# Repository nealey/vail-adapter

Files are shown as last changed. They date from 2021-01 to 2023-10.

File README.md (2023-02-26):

---
Author: neale
Email: neale@woozle.org
License: MIT
---

# Vail Adapter: Morse Code Key/Paddle to USB

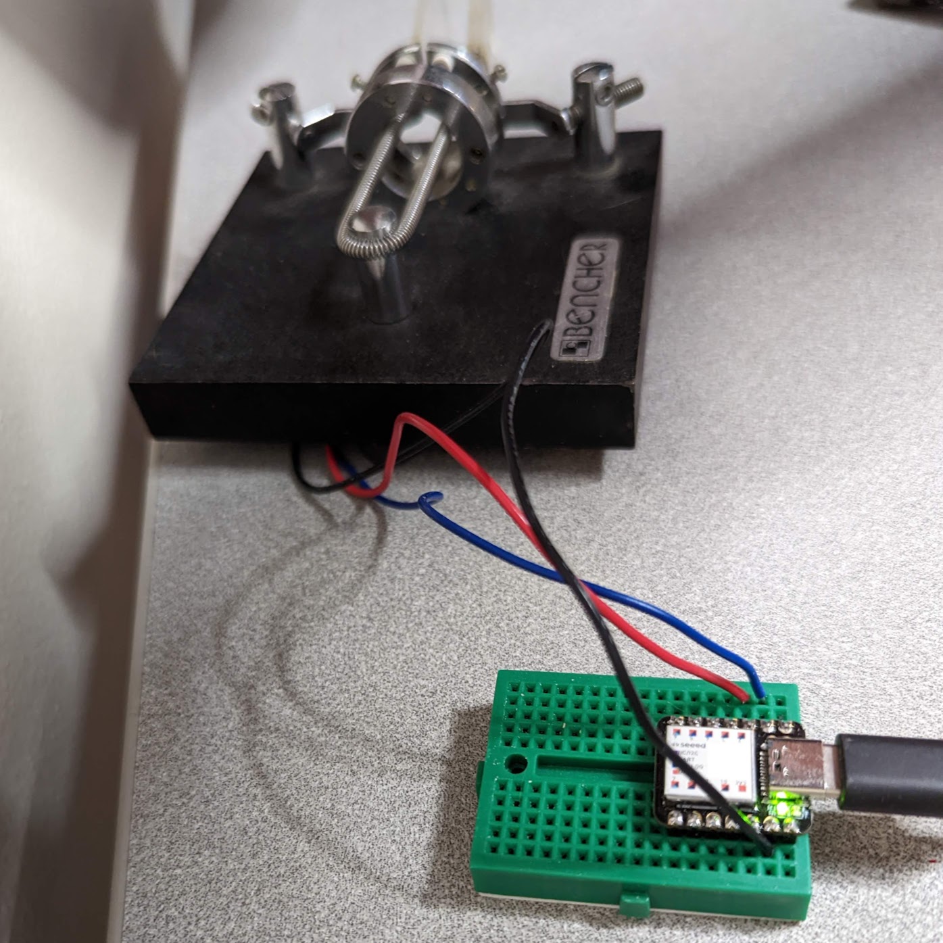
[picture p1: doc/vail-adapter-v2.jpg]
Vail adapter, assembled and connected


# Features

* Lets you key even if you move focus to another window
* Works with [Vail](https://vail.woozle.org/)
* Works with [VBand](https://hamradio.solutions/vband/), but the window has to remain focused
* Optional sidetone generator, which helps with latency
* Implements all nine keyer modes from Vail, in the adapter, so you lunatics can try to key at 50WPM with no latency issues
* Plays received signals in the adapter, so you can turn off your computer speaker
* Free firmware updates for life
* Can be wired up in about 5 minutes

[Vail Adapter benefits video](https://www.youtube.com/watch?v=XQ-mwdyLkOY) (4:46)

# Setting Up

* [Easy Setup](doc/easy-install.md)
* [Advanced Setup](doc/advanced-install.md)

# Future Work

Things I plan to add:

* [x] PCB to ease assembly and make a more robust shippable product
* [ ] Debug tone changes
* [ ] PCB v2 to get the speaker on pin 10 instead of pin 9
* [ ] Unplug detection: send a pulse out one pin and detect it on the T pin to reset straight-key detection

# Contributing
To contribute to this project please contact neale@woozle.org
https://id.arduino.cc/neale

# Similar projects

* Vail user Michele Giugliano's 
  [MorsePaddle2USB](https://github.com/mgiugliano/MorsePaddle2USB),
  which runs on a DigiSpark (attiny85). It only sends keystrokes, so you must keep the Vail
  window focused: you can't switch to other apps and still transimit.
* Ham Radio Solutions sells a 
  [USB Paddle Interface](https://hamradio.solutions/vband/)
  which appears to be very similar to Michele's project. You must keep the 
  Vail window focused.
* [CWKeyboard](https://github.com/kevintechie/CWKeyboard) looks almost 
  exactly the same as the VBand adapter.

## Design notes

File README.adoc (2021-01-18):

:Author: neale
:Email: neale@woozle.org
:Date: 2020-May-3
:Revision: 1
:License: MIT

= Project: USB Morse Adapter

image:https://lh3.googleusercontent.com/pw/ACtC-3d9xbLxL23QeLm-3gy3-Yt0VHE3IlQ-qyMDqTfdF6Bo7fHkkokACdIs68pmXevu14VzrrCeKj1JmRUiekUNiZe9J9rYIh_pTagvCbKSzpY8Ynp1m6cF4G_jTvti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["Vail adapter, assembled and connected",width=300,https://lh3.googleusercontent.com/pw/ACtC-3d9xbLxL23QeLm-3gy3-Yt0VHE3IlQ-qyMDqTfdF6Bo7fHkkokACdIs68pmXevu14VzrrCeKj1JmRUiekUNiZe9J9rYIh_pTagvCbKSzpY8Ynp1m6cF4G_jTvti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]

This translates Morse key inputs into USB events,
either MIDI or MIDI+Keyboard,
so you can use a computer.

I use this with an Internet morse code repeater I wrote,
available at https://vail.woozle.org/.
It will also work with [VBand](https://hamradio.solutions/vband/),
in MIDI+Keyboard mode.

This project requires an Arduino that can send USB.
The following should work:

=== Verified Working

* Seeeduino Xiao
* Arduino Micro
* KeeYees Pro Micro

=== Unverified but should work

Any USB-capable Arduino should be fine, including:

* Arduino Leonardo
* Arduino Zero
* Adafruit Trinket M0
* Adafruit GEMMA M0
* Adafruit Feather M0

You might even be able to get a Digispark (attiny85) to work,
but this may require a little hacking. Send me a patch, if you do!

== Step 1: Installation

If Arduino Create still exists when you're reading this,
you might be able to load up
https://create.arduino.cc/editor/neale/f94bb765-47bd-4bc4-9cbf-b978f7124bdc[my project]
and program your board without too much fuss.

Otherwise you are going to need to install the MidiUSB and Keyboard libraries.
These are highly popular libraries,
and there is much better documentation elsewhere on the Internet.

== Step 2: Assmble the circuit

=== For the impatient:

https://github.com/nealey/vail-adapter/wiki[Photos of assembled circuit]

Remember to jump pin 9 to ground for Firefox,
or VBand.

=== For the inquisitive:

Morse code keyers are very simple devices, 
they just connect two wires together.
You could use a button if you wanted to,
or even touch wires together.

The only real complication here is that some browsers
need to get keyboard events instead of musical instrument events.

=== Decide what browser you're going to use

Firefox needs a jumper between pin 9 and ground.
Just take a wire, and connect pin 9 directly to ground.
This puts the Arduino into "keyboard mode",
where it sends a comma for straight key,
and brackets for iambic.

If you don't connect pin 9 to ground,
the Arudino only sends MIDI (Musical Instrument Digital Interface)
events, so it looks like you hooked a piano up.
This works great in Chrome,
and lets you switch to other windows while still keying into vail.

=== Wire up your input device

Hook a straight key into ground on one side,
pin 10 on the other.
It's okay to leave pin 10 disconnected if you don't have a straight key.

Hook an iambic paddle in ground in the middle,
pins 11 and 12 on the outside posts.
It's okay to leave pins 11 and 12 disconnected if you don't have a paddle.

=== Using a headphone jack

If you prefer, you can wire a headphone jack up to GND, 11, and 12.
GND should be the sleeve, 11 the ring, and 12 the tip.

   o  --- 12
  |_| --- 11
  | | --- GND
  | |

Make sure any straight key you plug in has a TS adapter (mono plug):
this will short pin 11 to ground and signal to the Arduino to 
go into straight key mode.

You need to reset the Arduino if you change from an iambic to straight key.
On the micro, reset is a white button.

If you plug in your straight key and it looks like DAH is being held down,
it means you need to switch the connections to pins 11 and 12.

If you plug in your straight key and it looks like DIT is being held down,
it means you need to reset the Arduino to make it detect the key type again.

== Step 3: Load the code

Upload the code contained in this sketch on to your board.

== Step 4: Test it out

Make sure it's plugged in to your computer's USB port.

If you connected pin 9 to ground,
Open anything where you can type,
type in "hello", and hit the straight key.
You should see a comma after your hello.

Now you can open https://vail.woozle.org/,
click the "KEY" button once to let the browser know it's okay to make sound,
and you should be able to wail away on your new USB keyer.

=== License

This project is released under an MIT License.

Copyright © 2020 Neale Pickett
Copyright © 2013 thomasfredericks

Permission is hereby granted, free of charge, to any person obtaining a copy of
this software and associated documentation files (the "Software"), to deal in
the Software without restriction, including without limitation the rights to
use, copy, modify, merge, publish, distribute, sublicense, and/or sell copies of
the Software, and to permit persons to whom the Software is furnished to do so,
subject to the following conditions:

The above copyright notice and this permission notice shall be included in all
copies or substantial portions of the Software.

The software is provided "as is", without warranty of any kind, express or
implied, including but not limited to the warranties of merchantability, fitness
for a particular purpose, and noninfringement. In no event shall the authors or
copyright holders be liable for any claim, damages, or other liability, whether
in an action of contract, tort or otherwise, arising from, out of, or in
connection with the software or the use or other dealings in the software.

=== Contributing
To contribute to this project please contact neale@woozle.org
https://id.arduino.cc/neale

=== BOM

In addition to a key, some hookup wires, and a USB cable,
you only need a USB-capable Arduino: see above.

Since I don't know what might try to parse this section,
I'm calling for an Arduino Micro. But, really, many options
will work fine.

|===
| ID | Part name      | Part number | Quantity
| A1 | Arduino Micro  | ABX00053    | 1
|===

=== Help

This document is written in the _AsciiDoc_ format, a markup language to describe documents.
If you need help you can search the http://www.methods.co.nz/asciidoc[AsciiDoc homepage]
or consult the http://powerman.name/doc/asciidoc[AsciiDoc cheatsheet]

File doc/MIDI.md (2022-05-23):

# Vail MIDI Protocol

When it boots,
the Vail adapter sends left and right Control keyboard key up and down events.
It also shows up as a MIDI device.

The Vail web site sends MIDI control commands to enable MIDI keyer mode,
tells the keyer what sideband pitch to generate,
and can set the keyer mode.

## Controller 0 - MIDI Mode

`b0 00 ff` will enable MIDI mode and disable Keyboard mode

`b0 00 00` will enable Keyboard mode and disable MIDI mode

## Controller 1 - dit length

`b0 00 xx` will set the dit duration to `xx` times 2 milliseconds

## Controller 2 - sidetone note

`b0 00 xx` will play note `xx` as the sidetone note

## Program Change

`c0 xx` will change the keyer mode to `xx`.

### Keyer Modes

* 0: passthrough (sends C# and D for dit and dah)
* 1: cootie / straight key
* 2: bug
* 3: electric bug
* 4: single dot
* 5: ultimatic
* 6: plain iambic
* 7: iambic a
* 8: iambic b
* 9: keyahead

Any other mode will set to passthrough.

## Notes (key down / key up)

`90 00 xx` will begin playing note `xx`  
`80 00 xx` will end playing note `xx`

These work just like a regular MIDI synthesizer.

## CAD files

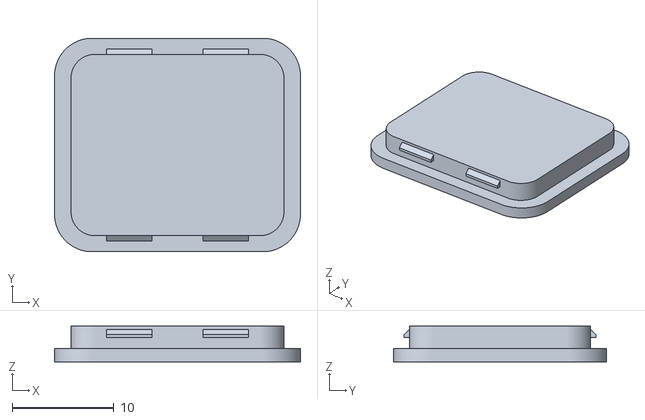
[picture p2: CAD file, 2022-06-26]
case/cap.stl
24.2 x 21.0 x 3.50

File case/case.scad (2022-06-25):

// Make circles lovely and round
$fa = 1; $fs = 0.1;

outer_dimensions = [24.2, 21, 25];
outer_radius = 3.7;
wall_width = [1.3, 1.3, 1.3];
inner_dimensions = outer_dimensions - (wall_width * 2);
inner_radius = outer_radius * 0.64;
z_elevate = [[0, 0, 0], [0, 0, 0], [0, 0, 0.5]]; // Multiply by this to bring bottom to z=0
center = [[-0.5, 0, 0], [0, -0.5, 0], [0, 0, 0]]; // Multiply by this to center something on the xy axes
xiao_elevation = 5.2; // Center of the PCB
pcb_thickness = 1.8;
channel = [16, 1, 1]; // Difensions of cap channel
channel_height = 2; // How far into the case the clips need to go
cap_thickness = 1.3;

module roundedcube(size=[1, 1, 1], center=false, r=0.5) {
    size = (size[0]==undef) ? [size, size, size] : size;
    cubeSize = [size[0] - 2*r, size[1] - 2*r, size[2]];

    translate(center ? [0,0,0] : size/2) {
        union() {
            cube([size[0], cubeSize[1], size[2]], center=true);
            cube([cubeSize[0], size[1], size[2]], center=true);
            for (ymul = [-0.5, 0.5]) {
                for (xmul = [-0.5, 0.5]) {
                    translate([cubeSize[0]*xmul, cubeSize[1]*ymul, 0]) cylinder(h=size[2], r=r, center=true);
                }
            }
        }
    }
}

module trs_support() {
    intersection() {
        cube([10, 30, 12], center=true);
        rotate(-45, [0, 1, 0]) cube([10, 30, 12], center=true);
    }
}

module usb_c() {
    cube([10, 6.5, 3.15], center=true);
    translate([0, -3.25, 0]) rotate(90, [0, 1, 0]) cylinder(d=3.15, h=10, center=true);
    translate([0, 3.25, 0]) rotate(90, [0, 1, 0]) cylinder(d=3.15, h=10, center=true);
}


module case() {
    difference() {
        translate((outer_dimensions * z_elevate) + ([0, 0, -1] * cap_thickness)) {
            difference() {
                roundedcube(outer_dimensions, center=true, r=outer_radius);
                roundedcube(inner_dimensions, center=true, r=inner_radius);
                translate(-outer_dimensions/2) cube([100, 100, cap_thickness]);
            }
        }

        // USB C port
        translate([inner_dimensions[0]/2, 0, 0]) {
            translate([0, 0, xiao_elevation - 3.15/2]) usb_c();
            cube([10, 9.65, xiao_elevation*2 - 3.15], center=true);
        }

    }
}

module body() {
    difference() {
        union() {
            case();

            // Add some supports
            intersection() {
                union() {
                    translate([13, 10, 13]) rotate(60, [0, 0, 1]) trs_support();
                    translate([13, -10, 13]) rotate(-60, [0, 0, 1]) trs_support();

                    // Shelf for board to rest against
                    difference() {
                        translate([-8, 0, xiao_elevation]) cube([6, 19, 4], center=true);
                        translate([-6, 0, xiao_elevation]) rotate(45, [0, 0, 1]) cube(15, center=true);
                    }
                }
                translate(outer_dimensions * center) roundedcube(outer_dimensions, r=outer_radius);
            }


            // Eyes
            translate([-12, 4, 18]) sphere(r=1.2);
            translate([-12, -4, 18]) sphere(r=1.2);
        }

        // Smirk grin
        intersection() {
            translate([0, 0, 11]) rotate(90, [0, 1, 0]) {
                difference() {
                    cylinder(h=50, d=20, center=true);
                    cylinder(h=50, d=19, center=true);
                }
            }
            translate([-18.7, 0, 0]) cube(7);
        }

        // Channel in the back to make it easier to squeeze in the XIAO
        translate([-4.5, 0, xiao_elevation]) intersection() {
            cube([13, 100, pcb_thickness], center=true);
            roundedcube(inner_dimensions, center=true, r=cap_thickness);
        }

        // Channels for bottom insertion part thingy
        for (i = [-0.5, 0.5]) {
            translate([0, inner_dimensions[1]*i, channel_height-channel[2]/2]) {
                cube(channel, center=true);
            }
        }

        // Paddle contacts
        translate([0, 0, 10]) {
            // 8-32x 1/4 screws
            rotate(90, [1, 0, 0]) cylinder(h=30, d=4.0, center=true);

            // Hookup wire
            translate([0, 0, -2.5]) cube([1, 30, 0.8], center=true);
        }

        // 3.5mm TRS jack
        translate([10, 0, 14]) rotate(90, [0, 1, 0]) cylinder(h=3, d=6.0);

        // Piezo buzzer
        translate([0, 0, 10]) {
            translate([-12, 3.5, 0]) cube([5, 1, 1], center=true);
            translate([-12, -3.5, 0]) cube([5, 1, 1], center=true);
        }
    }
}

module cap() {
    inner = inner_dimensions * 0.97; // leave 5% slop
    union() {
        intersection() {
            roundedcube(outer_dimensions, center=true, r=outer_radius);
            translate([0, 0, cap_thickness/2]) cube([100, 100, cap_thickness], center=true);
        }
        intersection() {
            roundedcube(inner, center=true, r=inner_radius);
            translate(center * inner) cube([100, 100, cap_thickness+2.2]);
        }
        difference() {
            union() {
                for (i = [-0.5, 0.5]) {
                    translate([0, inner[1]*i, cap_thickness + channel_height - channel[2]*0.4]) { // 40% of channel z for slop
                        difference() {
                            cube(channel, center=true);
                            translate([0, channel[1]*i, channel[2]/2]) rotate(90*i, [1, 0, 0]) {
                                cube([channel[0], channel[1], channel[2]], center=true);
                            }
                        }
                    }
                }
            }
            cube([5, 200, 200], center=true);
            for (i = [-1, 1]) {
                translate([9.5*i, 0, 0]) cube([5, 200, 200], center=true);
            }
        }
    }
}

if (TARGET == "body") {
    body();
} else if (TARGET == "cap") {
    cap();
} else if (true == true) {
    color([0, 0.5, 0.5]) body();
    color([0.5, 0, 0.5]) translate([0, 0, -cap_thickness]) cap();
} else {
    roundedcube(10);
}

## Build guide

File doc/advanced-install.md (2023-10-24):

# Advanced Install

In the Arduino IDE, edit [vail-adapter.ino](../vail-adapter.ino) with the pins
you want to use on your device. 

You will need the MidiUSB and Keyboard libraries installed.
You can do this through the Library manager.

Then compile and upload the sketch.

## Works with no source code changes

* Seeeduino Xiao SAMD21
* Adafruit Qt Py SAMD21

## Known to work with source code changes

* Arduino Micro
* KeeYees Pro Micro
* Arduino Leonardo
* Arduino Zero
* Adafruit Trinket M0
* Adafruit GEMMA M0
* Adafruit Feather M0

## Will Not Work!

The RP2040 chip will not work, because it lacks a USB MCU,
needed by the MIDIUSB library. 
I'm listing specific devices here
in the hopes that seeing them crossed out will prevent people from
making a purchasing mistake!

* ~~Seeeduino Xiao RP2040~~ Will not work!
* ~~Adafruit Qt Pi RP2040~~ Will not work!
* ~~Any RP2040 Device~~ Will not work!

# Advanced Wiring

XIAO Pinout

* GND: Ground
* D2: Dit
* D1: Dah
* D0: Straight Key
* D10: Speaker or Passive piezo buzzer
* A6: Capacative Dit
* A7: Capacative Dah
* A8: Capacative Straight Key

## Using a headphone jack

You can wire a headphone jack up to GND, D1, and D2.
GND should be the sleeve, D1 the ring, and D2 the tip.

     o  --- D2 (tip, dit)
    |_| --- D1 (ring, dah)
    | | --- GND (sleeve)
    | |

## Sidetone generator

If you connect a buzzer or speaker to pin 10 on one leg,
and ground on the other,
the adapter will beep when you press the straight key.

This will help a lot if there is a noticeable delay between when you press the key
and when your computer starts making a local beeping sound.

If you feel like no matter what you do,
you're always getting DAH with your straight key,
you should try this.

## Capacative Touch

The adapter works as a capacative touch sensor,
like a touch lamp.

You might wire these pins to screws or conductive pads. 
These can be used instead of, or in additon to, the normal pins D0, D1, and D2.

You do not need a ground wire with capacative touch!

* Pin A6: Dit capacative touch
* Pin A7: Dah capacative touch
* Pin A8: Straight key capacative touch

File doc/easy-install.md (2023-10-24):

# Easy Installation

1. Get a Seeeduino XIAO SAMD21
2. Download the most recent XIAO SAMD21 firmware from
[releases](https://github.com/nealey/vail-adapter/releases)
3. [Enter bootloader mode](https://wiki.seeedstudio.com/Seeeduino-XIAO/#enter-bootloader-mode)
4. Copy the firmware onto the XIAO SAMD21

[Wideo walkthrough of firmware upload](https://www.youtube.com/watch?v=IgOdkUe5SMY) (3:07)

If you would like to use a different microcontroller,
see the [advanced install instructions](advanced-install.md).

# Wiring

XIAO Pinout

* GND: Ground (usually in the middle of the paddle)
* Pin D2: Dit (usually left paddle)
* Pin D1: Dah (usually right paddle)

If you'd like to wire up a TRS (headphone) jack;
or take advantage of some of the adapters other features,
such as dedicated straight key, sidetone generation,
or capacative touch,
see the [advanced install instructions](advanced-install.md).

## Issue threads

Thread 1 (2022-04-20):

ESP32 Bluetooth as a future suggestion

mgiugliano, 2022-04-20:
ESP32 and its Bluetooth capabilities might be an interesting "wire-less" route to consider (although powering the device would still be cumbersome).

Thank you for your continued efforts and updates :-)

WrathPak, 2025-04-18:
Hi! We are exploring wifi as a method to wirelessly connect with the vail server. I haven't looked into bluetooth much yet but I think someone in the discord has - I'll check and see where they got with it.

WrathPak, 2025-09-20:
Just an update here, this is still being explored. We have a basic prototype hardware dev platform that can support this now.

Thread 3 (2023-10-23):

Does this work with the Seeed Xiao RP2040?

15medium, 2023-10-23:
Does this work with the Seeed Xiao RP2040?
https://wiki.seeedstudio.com/XIAO-RP2040/
Holding the boot button and plugging it in brings up the device but nothing happens when I copy the vail-adapter.xiao.uf2 file to it.
Thanks,
Paul VA3ZC

nealey, 2023-10-23:
No, it doesn't. Thanks for sending me a compile error log in private email, that saved me a bunch of time.

I've updated the documentation to specifically mention the M0 as the board to get. I hope nobody else has tried to get it on the wrong board!

nealey, 2023-10-23:
Fixed in https://github.com/nealey/vail-adapter/commit/36cc1384431d4a01a2066e536f0696d9a95e30b6

Closed 2023-10-23.

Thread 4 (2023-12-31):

Key down LED

g7kse, 2023-12-31:
Hi Neale,

Just ordering some parts for this and will be putting this in a small enclosure from [Hammond](https://www.hammfg.com/files/parts/pdf/1455C801RD.pdf) that I tend to use a bit so I'll adapt the PCB that's in the repo to slide in. Just wondering if adding a key down (TX'ing) LED is possible. The enclosure is 'desktop' so less like the smaller ones and there's obviously loads of space on the board

I would have thought using the buzzer might be a solution without changing code but then I noticed that Pin 10 might be used instead of Pin 9.

Before i go and fab up some PCB's can you let me know if the pin allocations will change and if its practical to take an LED off the buzzer pin?

nealey, 2024-01-01:
Yes, there's a bug with the current PCB, thanks for reminding me. I just opened #4 to track this problem. If you'd like to submit a patch to the PCB files, that would be super great! I'm not very adept at the software that generated them: I don't even remember what it's called.

You should be able to hook an LED up instead of a speaker: I think it uses the same PWM code, so the LED will not be full brightness. I don't have anything nearby to test this out, but if you have a microcontroller, go ahead and hook a sacrificial LED up to it and report back on how it went! The LED should be fine, but you never know, so don't use your favorite LED ;)

A very small code change would make a TX LED easy on another pin. You could `pinMode(8, OUTPUT)` and then, in beginTx and endTx, add `digitalWrite(8, true)` and `digitalWrite(8, false)` respectively, to get that LED going. I'd be glad to accept a patch adding this in, as well: but please use a `#define` instead of a hard-coded pin number :)

nealey, 2024-03-14:
@g7kse I finally got around to investigating: it appears the PCB files checked in have the speaker wired up to the correct pin. The board has 2023-01-22 silkscreened onto it: the ones I ordered are 2023-01-21. I must have realized shortly after I submitted the order that the pin was wrong, fixed it in git, and not bothered ordering a new batch, because I broke out every pin on top of the board anyway.

Anyway, I am strongly opposed to changing pins in the code, so feel encouraged to rely on the current allocations!

I'm going to close this issue, but I'd love to hear if you had any success wiring an LED to the buzzer pin.

nealey, 2024-03-14:
update: the pins are wrong on the part in kicad! I'll fix this.

Closed 2024-03-14.

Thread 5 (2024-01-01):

PCB has wrong pin wired to speaker

nealey, 2024-01-01:
Oops, I hooked pin 9 to the speaker: it should be pin 10.

Someone needs to change the PCB files to use the pin 10 instead!

nealey, 2024-03-14:
It looks like I actually made that change one day after I ordered my current batch of PCBs. The new design also moves the 3.5mm jack over and adds space for a piezo.

nealey, 2024-03-14:
The XIAO pins are incorrectly labelled, actually!

Closed 2024-03-14.

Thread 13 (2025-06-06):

User Changeable Key Bindings When in Keyboard Mode

Nehem11e, 2025-06-06:
A tool that was critical in my Morse code practice was Morse Mania. Unfortunately it uses a non standard key to listen trigger dits and dahs.  Left and Right square brackets “[“  and  “]”

It would be cool if you could use the vail repeater website, where other settings are changed, to set a key binding for the dits and dahs.  Have that setting save to the adapter and then have the adapter send out the new key building

WrathPak, 2025-06-08:
ok, vail repeater is updated at https://vail.fly.dev/ - here is the tool to change it. it is ugly and needs some work, but works.

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

this was kinda  ahuge change to keyboard mode so we should test it a lot
will only accept letters, [ ] / \ leftcontrl right contrl and shift keys as key bindings right now. and there is no error feedback on the ui yet.

[xiao_non_pcb.uf2.zip](https://github.com/user-attachments/files/20642242/xiao_non_pcb.uf2.zip)
[xiao_basic_pcb_v2.uf2.zip](https://github.com/user-attachments/files/20642243/xiao_basic_pcb_v2.uf2.zip)
[xiao_basic_pcb_v1.uf2.zip](https://github.com/user-attachments/files/20642244/xiao_basic_pcb_v1.uf2.zip)
[qtpy_non_pcb.uf2.zip](https://github.com/user-attachments/files/20642245/qtpy_non_pcb.uf2.zip)
[qtpy_basic_pcb_v1.uf2.zip](https://github.com/user-attachments/files/20642240/qtpy_basic_pcb_v1.uf2.zip)
[qtpy_basic_pcb_v2.uf2.zip](https://github.com/user-attachments/files/20642241/qtpy_basic_pcb_v2.uf2.zip)

chickenside, 2025-08-24:
@WrathPak, that link no longer works.  I would also like to try this for Morse Mania.

Closed 2025-09-10.

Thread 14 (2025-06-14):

playVAIL startup function has extra ending dit

EvanBoyar, 2025-06-14:
The function is correctly written to play VAIL in CW.

However, it sounds like it plays an extra dit at the end.

I think what's going on is that adapter.cpp (see case 2 of your switch statement) when it loads from EEPROM, it plays a short confirmation tone that's around as long as a dit. I think you need to add a short delay of a couple hundred ms to have audible separation between the startup and the load completion sounds. Or maybe rm the conf tone if you only want it to say VAIL.

WrathPak, 2025-06-15:
Hi! Thanks for tracking this down - that was definitely it. HAd some confirmation tones there back in the day that I don't think we need now so I removed them. I'll make a new release shortly to address this!

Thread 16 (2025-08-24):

QT Py Advanced PCB UF2: Both paddles register as ControlLeft in keyboard mode

chickenside, 2025-08-24:
Vail Adapter hardware: Adafruit QT Py SAMD21 (M0), Advanced PCB build.  Firmware flashed: qtpy_advanced_pcb.uf2 from the latest release.

Observed behavior (keyboard mode):

In apps that accept keyboard paddles (e.g., VBand, Morse Invaders), paddles work for sending.

In generic key testers (e.g., [keycode.info]) and on [morsecode.world keyer], both paddles register only as ControlLeft. I never see ControlRight.

On the same system, a physical keyboard produces ControlLeft and ControlRight distinctly, so the OS/browser can differentiate the two keys.

Expected behavior:
In keyboard mode, one paddle should emit ControlLeft and the other ControlRight (VBand-style mapping) so sites like morsecode.world can bind both sides independently.

Question / Request:
Am I missing a configuration step for keyboard mode, or does the current QT Py SAMD21 (Advanced PCB) UF2 map both paddles to Left Ctrl? If it’s the latter, could the keyboard report be updated so the right paddle emits Right Ctrl?

Environment:

Board: Adafruit QT Py SAMD21 (M0), Advanced PCB

Firmware: qtpy_advanced_pcb.uf2 (latest release)

OS/Browser: Windows 10, Chrome and Firefox (same result)

Test pages: keycode.info, morsecode.world keyer

Thanks for confirming whether this is usage or a small firmware mapping fix.

WrathPak, 2025-09-20:
I have some time to look at this this weekend, I'll see what I can do.

WrathPak, 2025-10-04:
This has been solved now, and is fixed on the newest release available at https://www.update.vailadapter.com

Closed 2025-10-04.

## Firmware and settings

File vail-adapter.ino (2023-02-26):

// Copyright 2020 Neale Pickett
// Distributed under the MIT license
// Please see https://github.com/nealey/vail-adapter/

// MIDIUSB - Version: Latest 
#include <MIDIUSB.h>
#include <Keyboard.h>
#include <Adafruit_FreeTouch.h>
#include "bounce2.h"
#include "touchbounce.h"
#include "adapter.h"

#define DIT_PIN 2
#define DAH_PIN 1
#define KEY_PIN 0
#define QT_DIT_PIN A6
#define QT_DAH_PIN A7
#define QT_KEY_PIN A8
#define PIEZO 10
#define LED_ON false // Xiao inverts this logic for some reason
#define LED_OFF (!LED_ON)

#define DIT_KEYBOARD_KEY KEY_LEFT_CTRL
#define DAH_KEYBOARD_KEY KEY_RIGHT_CTRL
#define TONE 3000

#define MILLISECOND 1
#define SECOND (1 * MILLISECOND)

bool trs = false; // true if a TRS plug is in a TRRS jack
uint16_t iambicDelay = 80 * MILLISECOND;
Bounce dit = Bounce();
Bounce dah = Bounce();
Bounce key = Bounce();
TouchBounce qt_dit = TouchBounce();
TouchBounce qt_dah = TouchBounce();
TouchBounce qt_key = TouchBounce();
VailAdapter adapter = VailAdapter(PIEZO);

void setup() {
  pinMode(LED_BUILTIN, OUTPUT);
  dit.attach(DIT_PIN, INPUT_PULLUP);
  dah.attach(DAH_PIN, INPUT_PULLUP);
  key.attach(KEY_PIN, INPUT_PULLUP);
  qt_dit.attach(QT_DIT_PIN);
  qt_dah.attach(QT_DAH_PIN);
  qt_key.attach(QT_KEY_PIN);

  Keyboard.begin();

  // To auto-sense a straight key in a TRRS jack,
  // we just check to see if DAH is closed. 
  // The sleeve on the straight key's TRS plug
  // will short the second ring to the sleeve.
  for (int i = 0; i < 16; i++) {
    delay(20);
    dah.update();
  }
  if (dah.read() == LOW) {
    trs = true;
    key = dit;
  }
}

// A reentrant doodad to blink out the letter V at startup
// After startup, display the status of the keyboard
#define HELLO_BITS 0b0000101010111000
void setLED() {
  static bool beepin = false;
  int beat = millis() / iambicDelay;
  bool on = adapter.KeyboardMode(); // If we're not in intro, display status of keyboard

  if (beat < 16) {
    on = HELLO_BITS & (1 << (15-beat));
    if (on != beepin) {
      if (on) {
        tone(PIEZO, TONE);
      } else {
        noTone(PIEZO);
      }
      beepin = on;
    }
  }
  
  digitalWrite(LED_BUILTIN, on?LED_ON:LED_OFF);
}

void loop() {
  unsigned now = millis();  
  midiEventPacket_t event = MidiUSB.read();

  setLED();
  adapter.Tick(now);

  if (event.header) {
    adapter.HandleMIDI(event);
  }

  // Monitor straight key pin
  if (key.update() || qt_key.update()) {
    bool pressed = !key.read() || qt_key.read();
    adapter.HandlePaddle(PADDLE_STRAIGHT, pressed);
  }

  // If we made dit = dah, we have a straight key on the dit pin,
  // so we skip other keys polling.
  if (trs) {
    return;
  }

  if (dit.update() || qt_dit.update()) {
    bool pressed = !dit.read() || qt_dit.read();
    adapter.HandlePaddle(PADDLE_DIT, pressed);
  }
  
  if (dah.update() || qt_dah.update()) {
    bool pressed = !dah.read() || qt_dah.read();
    adapter.HandlePaddle(PADDLE_DAH, pressed);
  }
}

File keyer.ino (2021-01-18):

// Copyright 2020 Neale Pickett
// Distributed under the MIT license
// Please see https://github.com/nealey/vail-adapter/

// MIDIUSB - Version: Latest 
#include <MIDIUSB.h>
#include <Keyboard.h>
#include "bounce2.h"

#define DIT_PIN 12
#define DAH_PIN 11
#define KEY_PIN 10
#define KBD_PIN 9

#define STRAIGHT_KEY ','
#define DIT_KEY '['
#define DAH_KEY ']'

bool iambic = true;
Bounce kbd = Bounce();
Bounce dit = Bounce();
Bounce dah = Bounce();
Bounce key = Bounce();

void setup() {
  pinMode(LED_BUILTIN, OUTPUT);
  kbd.attach(KBD_PIN, INPUT_PULLUP);
  dit.attach(DIT_PIN, INPUT_PULLUP);
  dah.attach(DAH_PIN, INPUT_PULLUP);
  key.attach(KEY_PIN, INPUT_PULLUP);
  
  Keyboard.begin();

  // Straight keys need to wire the dah pin to ground somehow.
  // The easiest way I can think of to do this is to use a TS connector
  // instead of a TRS connector.
  for (int i = 0; i < 16; i++) {
    dah.update();
  }
  if (dah.read() == LOW) {
    iambic = false;
  } else {
    iambic = true;
  }
  
  digitalWrite(LED_BUILTIN, !iambic);
}

void midiKey(bool down, uint8_t key) {
  midiEventPacket_t event = {down?9:8, down?0x90:0x80, key, 0x7f};
  MidiUSB.sendMIDI(event);
  MidiUSB.flush();
}

void loop() {
  bool keyboard;
  
  kbd.update();
  keyboard = !kbd.read();

  // Monitor straight key pin
  if (key.update()) {
    midiKey(key.fell(), 0);
    if (keyboard) {
      if (key.fell()) {
        Keyboard.press(STRAIGHT_KEY);
      } else {
        Keyboard.release(STRAIGHT_KEY);
      }
    }
  }
  
  // Monitor dit pin, which could be straight key if dah was closed on boot
  if (dit.update()) {
    uint8_t kbdKey, mKey;
    if (iambic) {
      kbdKey = DIT_KEY;
      mKey = 1;
    } else {
      kbdKey = STRAIGHT_KEY;
      mKey = 0;
    }
    
    midiKey(dit.fell(), mKey);
    if (keyboard) {
      if (dit.fell()) {
        Keyboard.press(kbdKey);
      } else {
        Keyboard.release(kbdKey);
      }
    }
  }
  
  // Monitor dah pin
  if (iambic && dah.update()) {
    midiKey(dah.fell(), 2);
    
    if (keyboard) {
      if (dah.fell()) {
        Keyboard.press(DAH_KEY);
      } else {
        Keyboard.release(DAH_KEY);
      }
    }
  }
}

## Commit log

2020-05-16 Link to arduino create project
2020-05-16 unweird case
2021-01-18 Document other working boards
2022-04-20 Many changes for v2
    * Send left and right ctrl, VBand's secret keys for their adapter
    * Flash lights twice at bootup
    * LED reflects whether keyboard mode is enabled
    * MIDI receive: if you release key C0, we stop sending keyboard events
    * Get rid of the "keyboard mode" pin
    * Add Makefile so I don't have to use Arduino IDE
2022-04-20 Update firmware filename to reflect board
2022-04-22 Sound piezo buzzer for straight key
    [vail-adapter.ino]
2022-04-22 Straight key buzzer on pin 7
    [vail-adapter.ino]
2022-04-22 Fix bug where dit is never released in kbd mode
    [vail-adapter.ino]
2022-05-22 Lots of changes for V3.0:
    [adapter-case.scad, case.stl, paddles.scad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]
2022-05-29 Update case design
    [adapter-case.scad]
2022-05-30 Smaller audio jack hole
    [adapter-case.scad]
2022-05-31 Version I built for dad
    [adapter-case.scad]
2022-05-31 make holes a bit bigger
    [adapter-case.scad]
2022-06-11 Pretty good piggy
    [adapter-case.scad, adapter-lid.scad, adapter-lid.stl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]
2022-06-12 Rework case to be rounded
    [adapter-case.scad, adapter-lid.scad, case.scad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]
2022-06-12 More case work
    [adapter-lid.stl, cap.stl]
2022-06-25 possibly-working pig
    [case.scad]
2022-06-26 Case work, bugfixes
    [cap.stl]
2023-01-22 First try at a PCB
    [pcb.kicad_sch]
2023-01-22 More svelte PCB
2023-02-26 Actually change pitch, fix VBand LED
    * Fix VBand compatability LED
    * Make it actually change pitch
    [vail-adapter.ino]
2024-03-14 Route buzzer to XIAO pin 10, not 9. New KiCAD.
    Fixes #5
    [pcb.kicad_sch]
2024-10-20 Revert "Begin work on standalone websocket client"
    This reverts commit 38cf3f535d26e55e8258adbbc53c8ee800fe757a.
    [vail-adapter.ino]
